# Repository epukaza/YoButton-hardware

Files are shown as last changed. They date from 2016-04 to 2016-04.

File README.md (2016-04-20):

## YoButton hardware
Hardware for the Yo button, including primitive plastic model, uses an an ESP8266 to handle the Wi-Fi, and and MSP430 to handle USB negotiation for 500 ma charging and power to enable long standby times. Code for the ESP and MSP uC's is currently private

Board made in Eagle, PDF file of the schematic is supplied in the repo, direct link [here](https://github.com/epukaza/YoButton-hardware/raw/master/schematic.pdf)

# Board images:

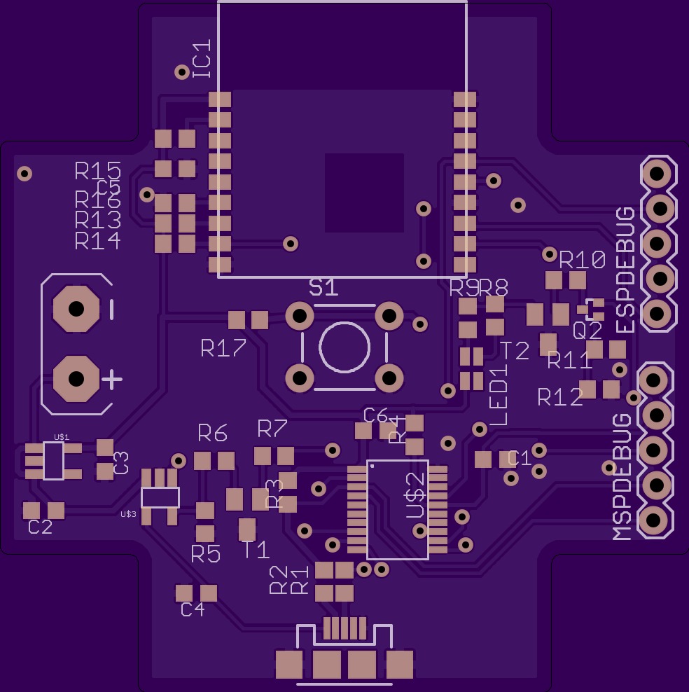
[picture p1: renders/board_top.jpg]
board top


# Renders:

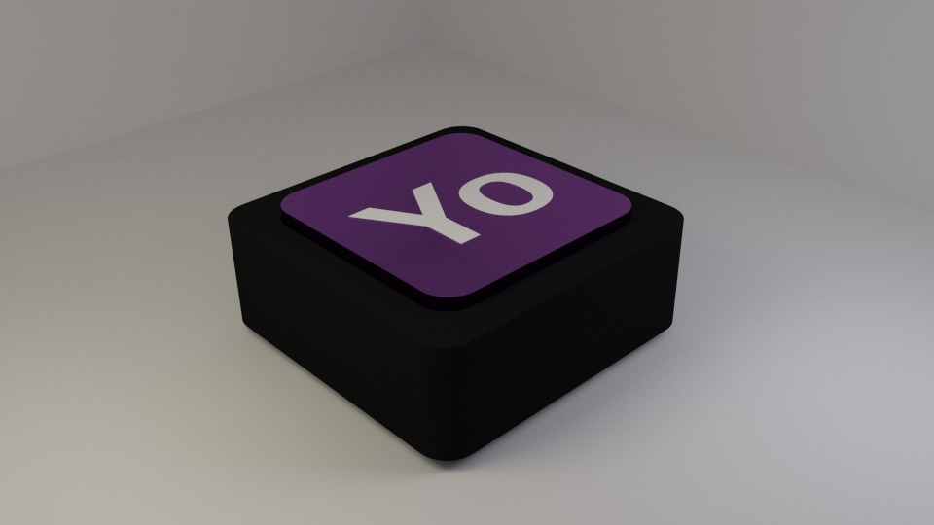
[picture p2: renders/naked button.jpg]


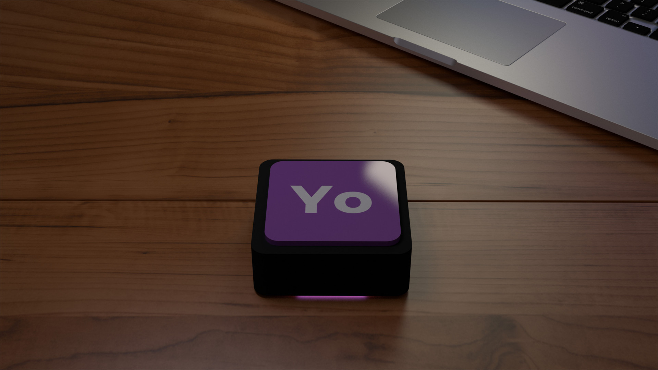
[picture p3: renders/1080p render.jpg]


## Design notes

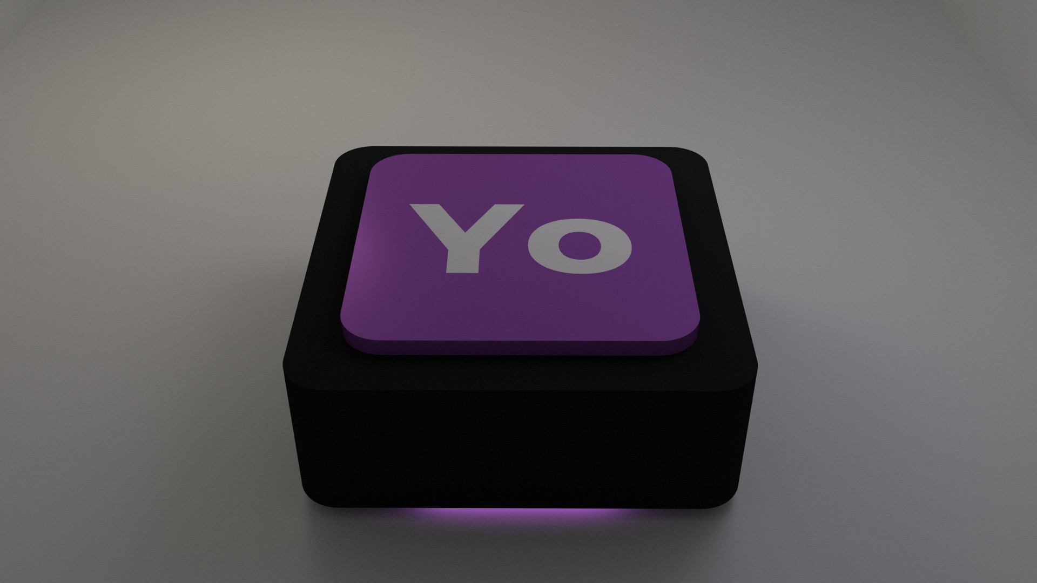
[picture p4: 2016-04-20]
renders/naked button_front_underglow.jpg

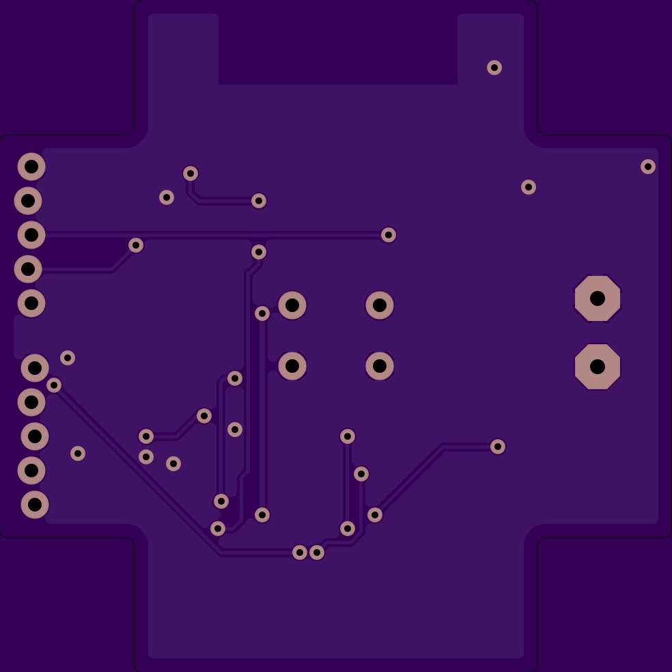
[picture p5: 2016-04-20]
renders/board_bottom.jpg

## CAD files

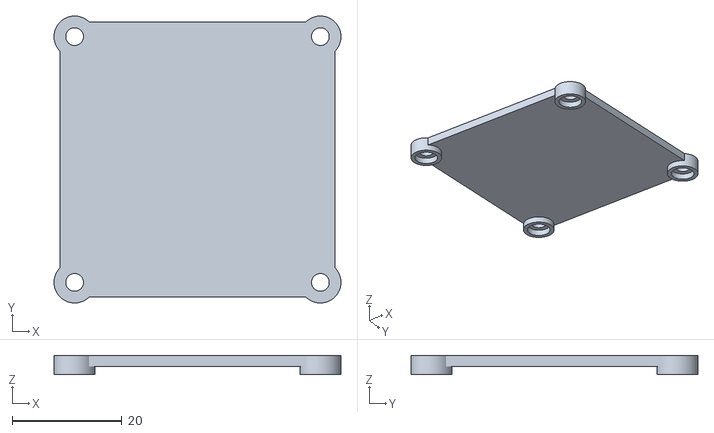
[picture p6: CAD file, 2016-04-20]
plastic model/Yo Button - Baseplate.stl
52.2 x 52.2 x 3.50

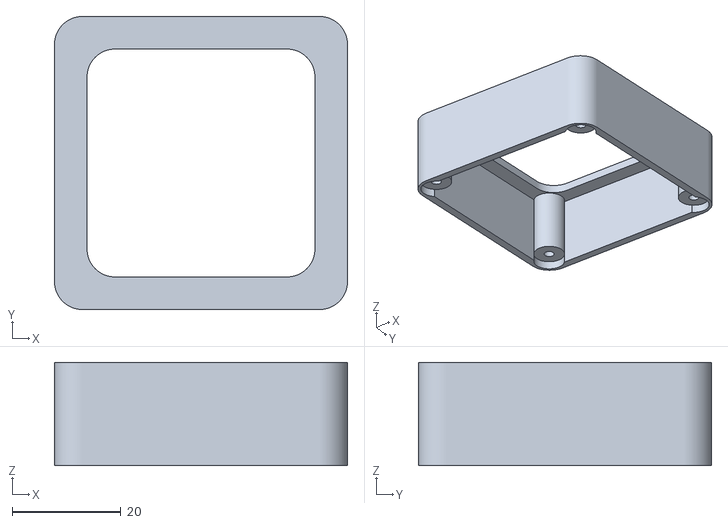
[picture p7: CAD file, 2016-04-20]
plastic model/Yo Button - Body.stl
54.0 x 54.0 x 19.0

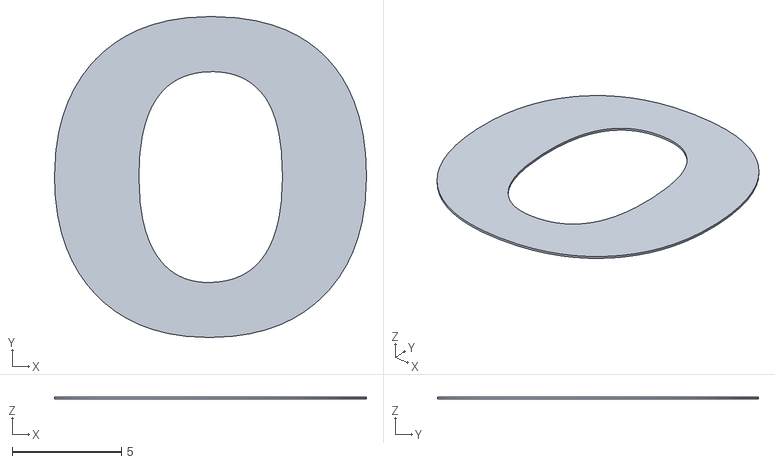
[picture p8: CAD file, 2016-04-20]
plastic model/Yo Button - O.stl
14.3 x 14.7 x 0.1

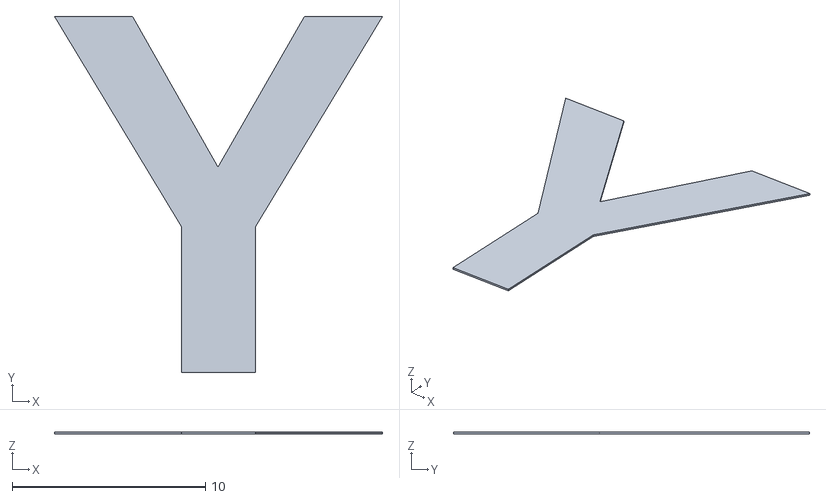
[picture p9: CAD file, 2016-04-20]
plastic model/Yo Button - Y.stl
17.0 x 18.4 x 0.1

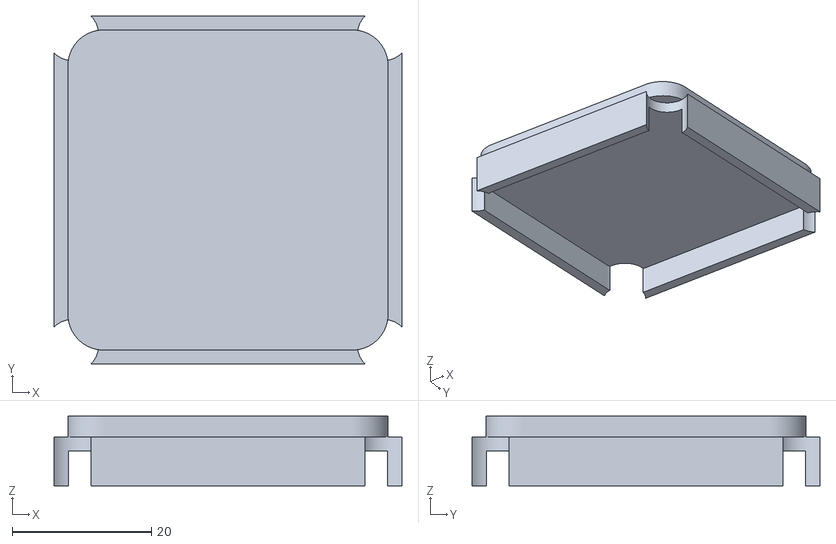
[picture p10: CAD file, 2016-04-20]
plastic model/Yo Button - Top.stl
50.0 x 50.0 x 10.0

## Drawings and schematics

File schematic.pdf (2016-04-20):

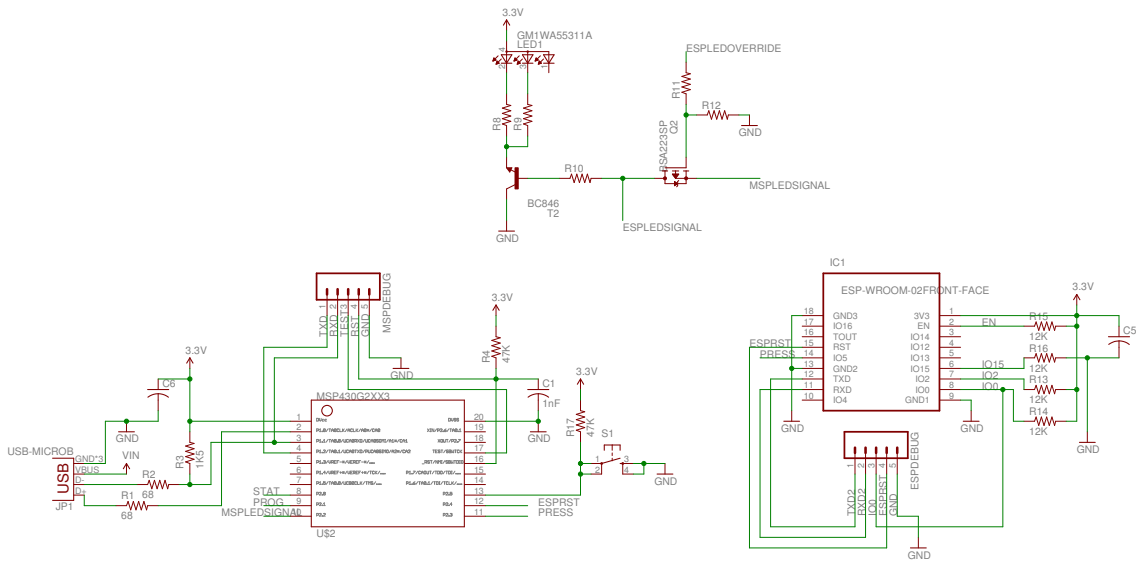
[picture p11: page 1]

2 | 19 18 17

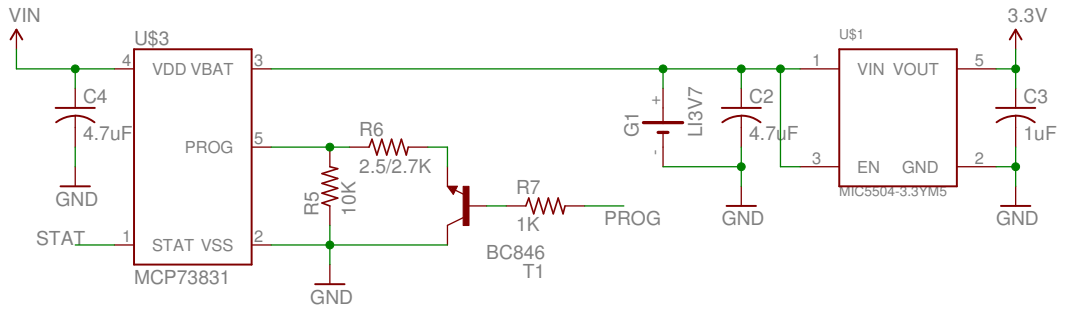
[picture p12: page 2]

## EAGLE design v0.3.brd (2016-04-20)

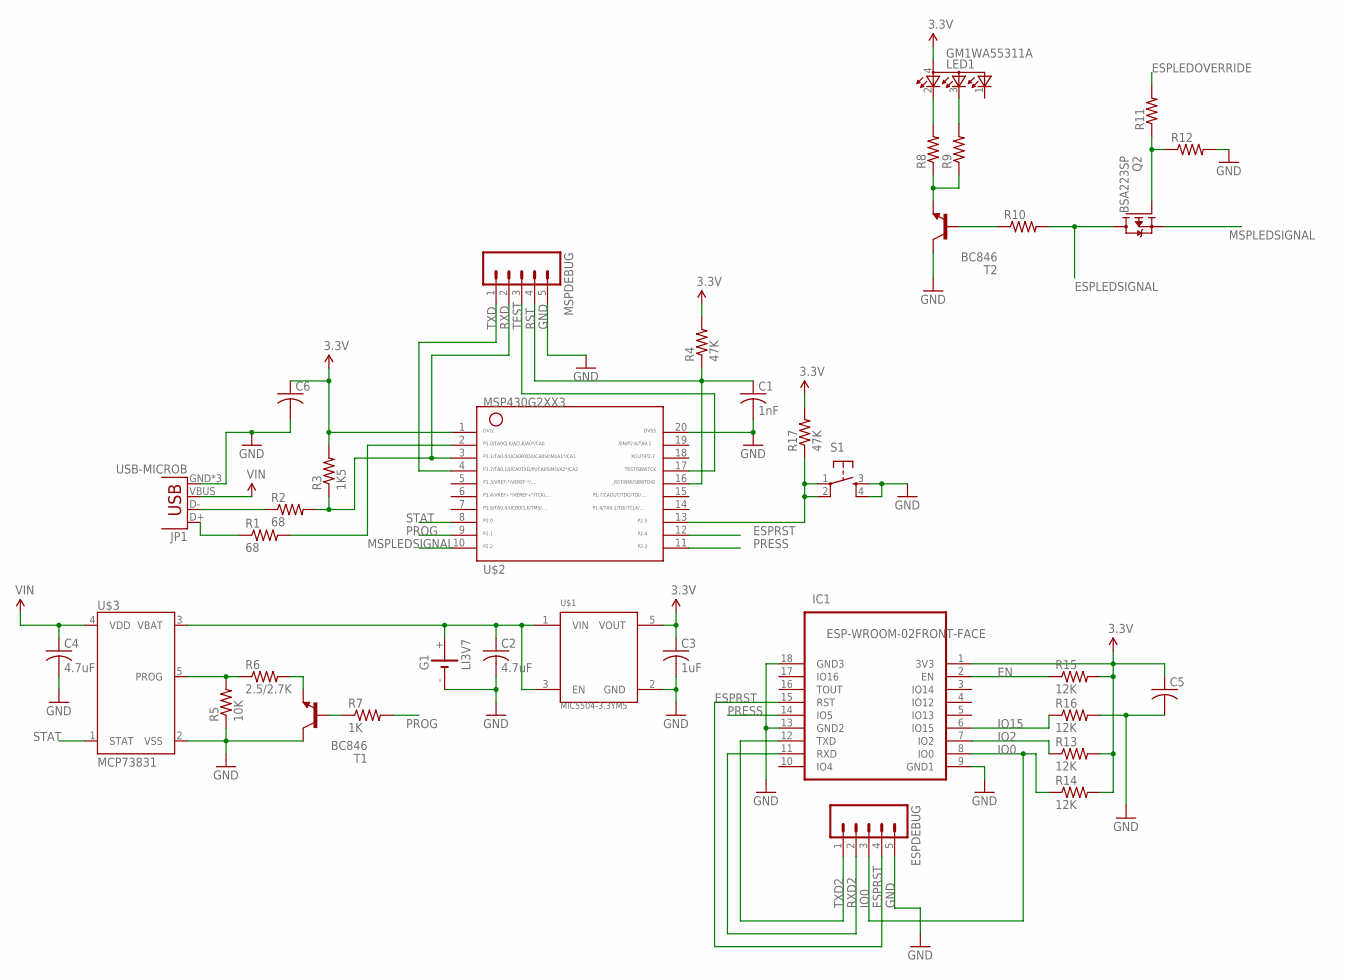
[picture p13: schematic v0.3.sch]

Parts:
C1: 1nF; C0603K
C2, C4: 4.7uF; C0603K
C3: 1uF; C0603K
C5, C6: C-USC0603K; C0603K
ESPDEBUG: M05LOCK; 1X05_LOCK
G1: LI3V7
IC1: ESP-WROOM-02FRONT-FACE; FRONT-FACE
JP1: USB-MICROB
LED1: GM1WA55311A
MSPDEBUG: M05LOCK; 1X05_LOCK
Q2: BSA223SP; SC75_INFINEON
R1, R2: 68; R0603
R3: 1K5; R0603
R4, R17: 47K; R0603
R5: 10K; R0603
R6: 2.5/2.7K; R0603
R7: 1K; R0603
R8, R9, R10, R11, R12: R-US_R0603; R0603
R13, R14, R15, R16: 12K; R0603
S1: TAC_SWITCHPTH; TACTILE-PTH
T1, T2: BC846; SOT23
U$1: MIC5504-3.3YM5; SOT23-5
U$2: G2XX3---PW20; PW20
U$3: MCP73831; SOT23-5

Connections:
3.3V: C3.1, C5.1, C6.1, IC1.1 (3V3), LED1.4 (A), R3.2, R4.2, R13.2, R14.2, R15.2, R17.2, U$1.5 (VOUT), U$2.1
EN: IC1.2 (EN), R15.1
ESPLEDOVERRIDE: R11.2
ESPLEDSIGNAL: Q2.2 (D), R10.2
ESPRST: ESPDEBUG.4, IC1.15 (RST), U$2.12
GND: C1.2, C2.2, C3.2, C4.2, C5.2, C6.2, ESPDEBUG.5, G1.-, IC1.9 (GND1), IC1.13 (GND2), IC1.18 (GND3), JP1.GND, JP1.MT1 (GND), JP1.MT2 (GND), MSPDEBUG.5, R5.1, R12.2, R16.2, S1.3, S1.4, T1.3 (C), T2.3 (C), U$1.2 (GND), U$2.20, U$3.2 (VSS)
IO0: ESPDEBUG.3, IC1.8 (IO0), R14.1
IO2: IC1.7 (IO2), R13.1
IO15: IC1.6 (IO15), R16.1
MSPLEDSIGNAL: Q2.3 (S), U$2.10
unnamed: R5.2, R6.1, U$3.5 (PROG)
unnamed: JP1.D+, R1.1
unnamed: JP1.D-, R2.1
unnamed: R1.2, U$2.2
unnamed: C2.1, G1.+, U$1.1 (VIN), U$1.3 (EN), U$3.3 (VBAT)
unnamed: R6.2, T1.2 (E)
unnamed: R7.1, T1.1 (B)
unnamed: R17.1, S1.1, S1.2, U$2.13
unnamed: LED1.2 (CRED), R8.2
unnamed: LED1.3 (CBLUE), R9.2
unnamed: R10.1, T2.1 (B)
unnamed: R8.1, R9.1, T2.2 (E)
unnamed: Q2.1 (G), R11.1, R12.1
PRESS: IC1.14 (IO5), U$2.11
PROG: R7.2, U$2.9
RST: C1.1, MSPDEBUG.4, R4.1, U$2.16
RXD: MSPDEBUG.2, R2.2, R3.1, U$2.3
RXD2: ESPDEBUG.2, IC1.11 (RXD)
STAT: U$2.8, U$3.1 (STAT)
TEST: MSPDEBUG.3, U$2.17
TXD: MSPDEBUG.1, U$2.4
TXD2: ESPDEBUG.1, IC1.12 (TXD)
VIN: C4.1, JP1.VBUS, U$3.4 (VDD)

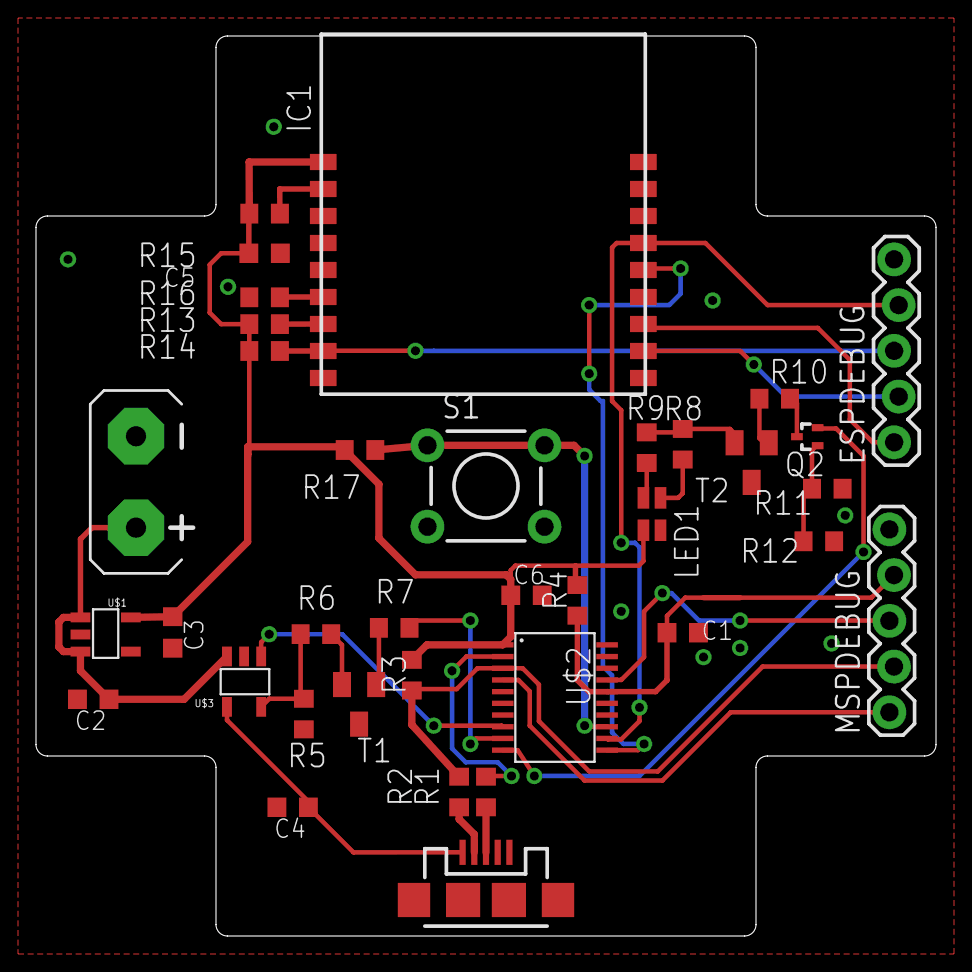
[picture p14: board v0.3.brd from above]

Board: 2 copper layers, 50.0 x 50.0 mm, 36 parts (0 on the bottom side), 32 nets.

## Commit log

2016-04-20 Share project on github
    [Yo Button - Baseplate.stl, Yo Button - Body.stl, Yo Button - O.stl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]
2016-04-20 slight cosmetic update and added gitignore
    [v0.3.brd, v0.3.sch]
2016-04-20 add board images
2016-04-20 add schematic pdf

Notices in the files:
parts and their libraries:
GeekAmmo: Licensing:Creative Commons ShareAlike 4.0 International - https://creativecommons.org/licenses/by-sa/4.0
